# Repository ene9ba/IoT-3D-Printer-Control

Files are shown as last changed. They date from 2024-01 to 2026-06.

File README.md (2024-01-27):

# IoT-3D-Printer-Control
Control Unit with ESP 8266 to control enclosure LED, cabon filter and analyse Temperature, Fan-Spee, Flamesensor, Smokesensor

CAD files you can find at [grabcad](https://grabcad.com/library/3d-printer-enclosure-7) or [thingeverse](https://www.thingiverse.com/thing:6453549)

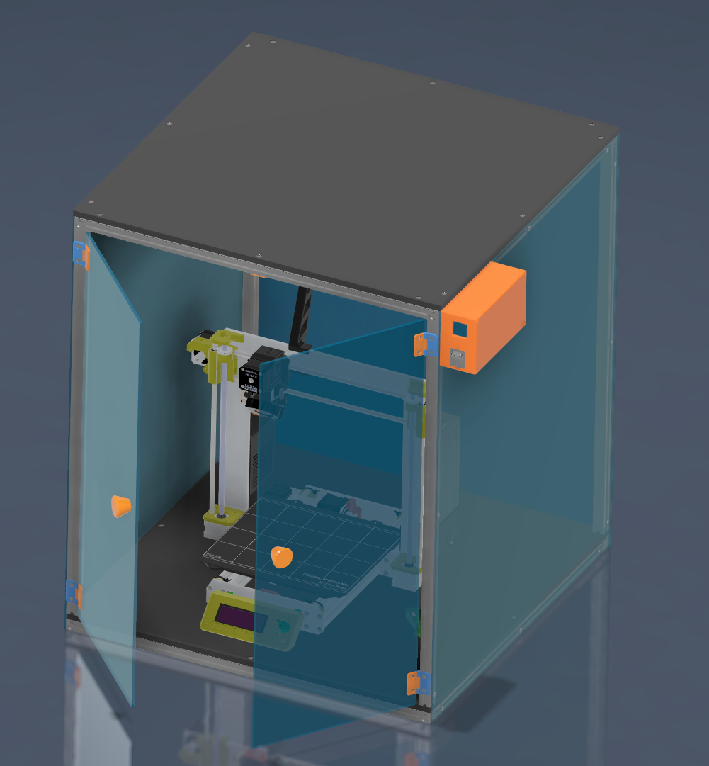
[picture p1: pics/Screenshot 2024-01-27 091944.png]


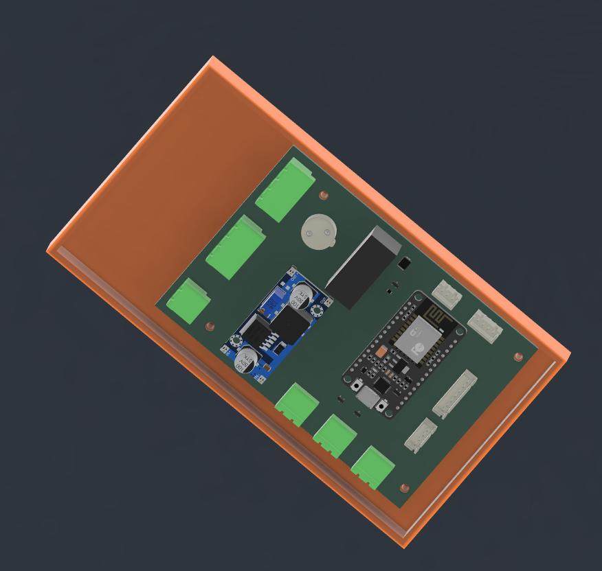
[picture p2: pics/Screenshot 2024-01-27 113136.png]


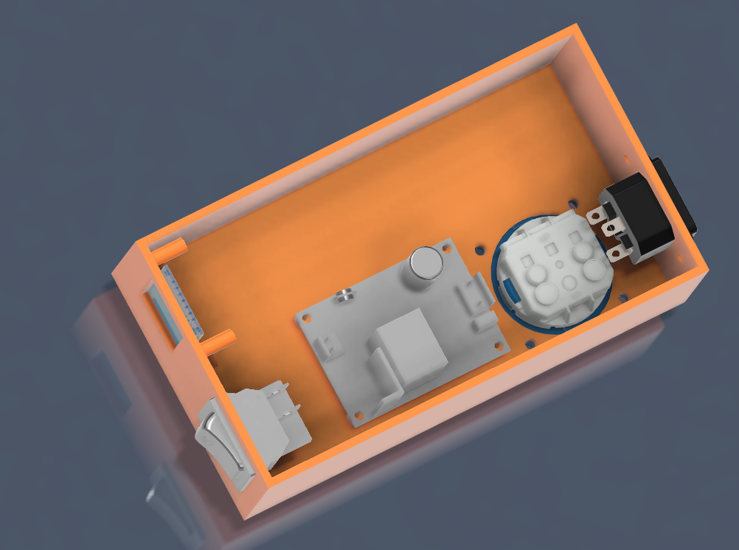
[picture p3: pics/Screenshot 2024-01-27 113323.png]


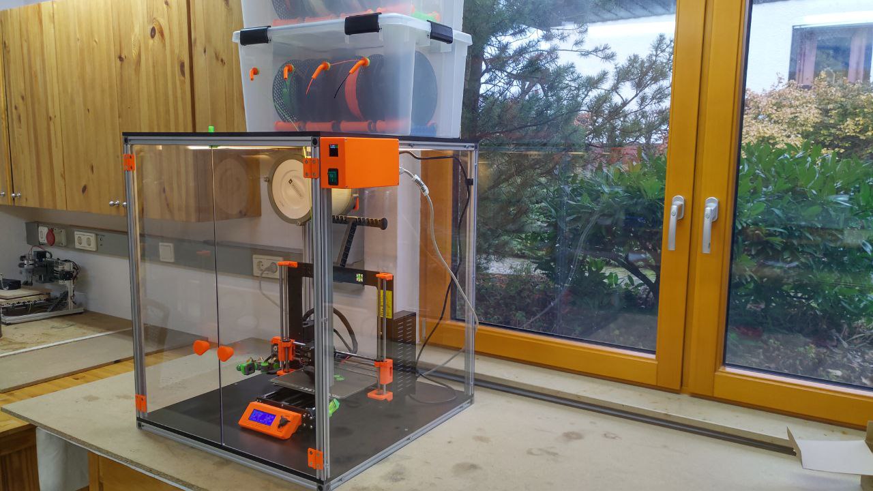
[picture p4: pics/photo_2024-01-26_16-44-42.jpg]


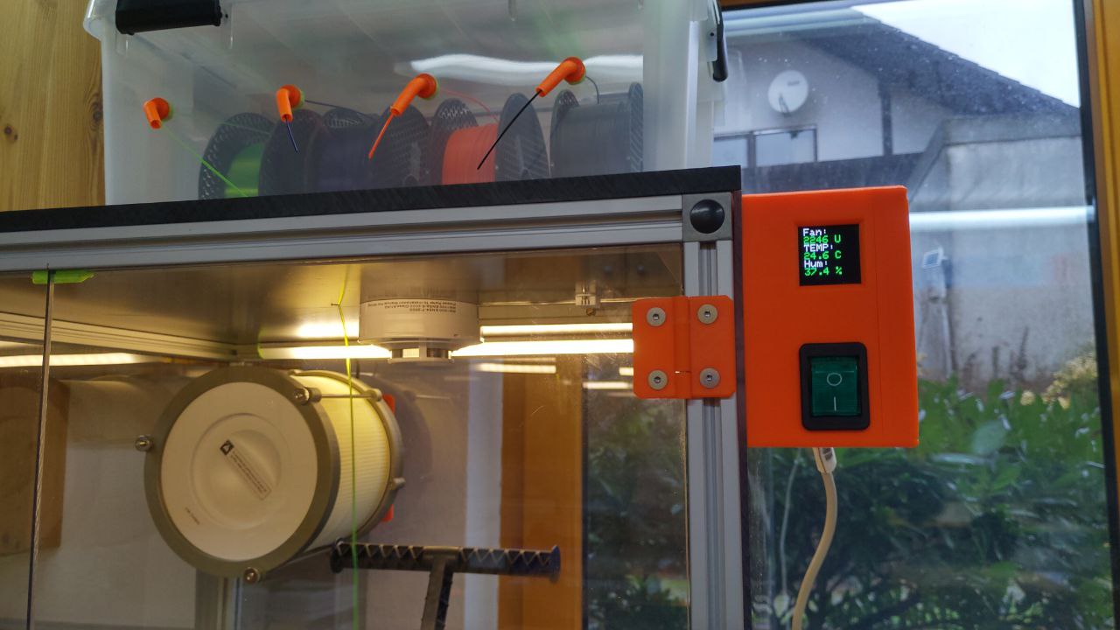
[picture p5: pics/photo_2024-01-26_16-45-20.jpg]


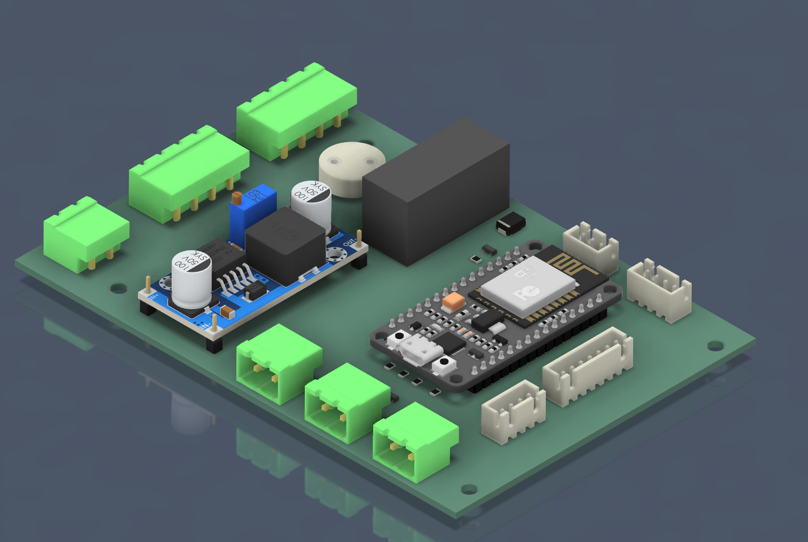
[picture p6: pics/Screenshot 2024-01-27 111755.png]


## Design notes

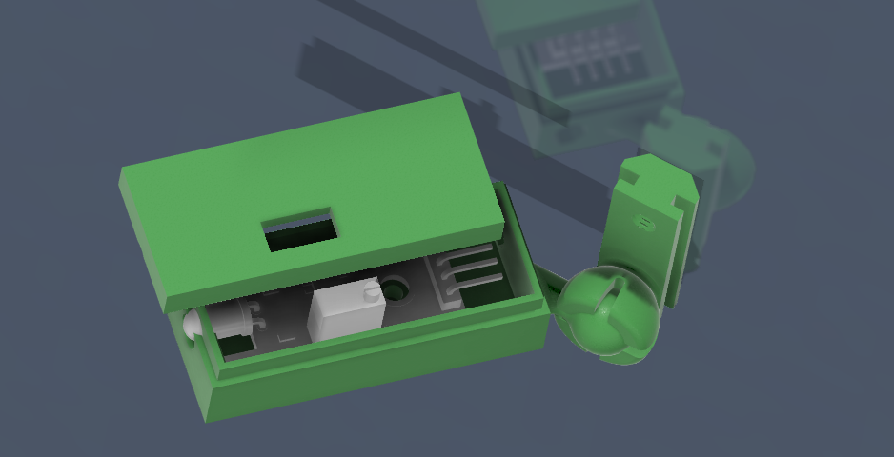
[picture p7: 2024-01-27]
pics/Screenshot 2024-01-27 111642.png

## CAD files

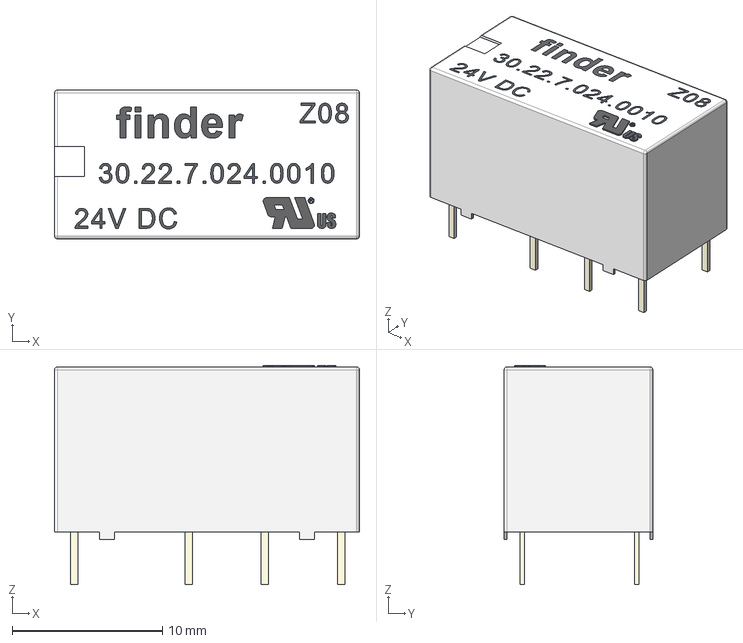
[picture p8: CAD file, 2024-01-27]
Hardware/Cabinetcontrol1/Step/relay_finder_30_22_7_024_0010.step
20.3 x 9.90 x 14.6 mm

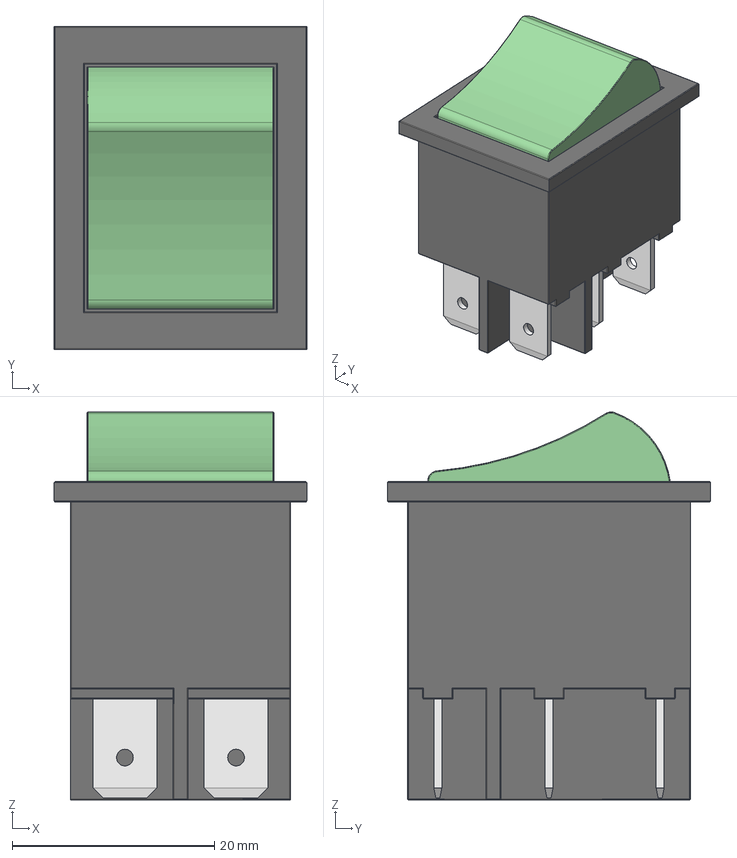
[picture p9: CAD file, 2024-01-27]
Hardware/Cabinetcontrol1/Step/Wippschalter mit Beleuchtung Serie 3652.step
25.0 x 32.0 x 38.4 mm
Flachstecker 6,3mm x 6
Schalter Körper
Grundkoerper ohne Beruehungsschutz

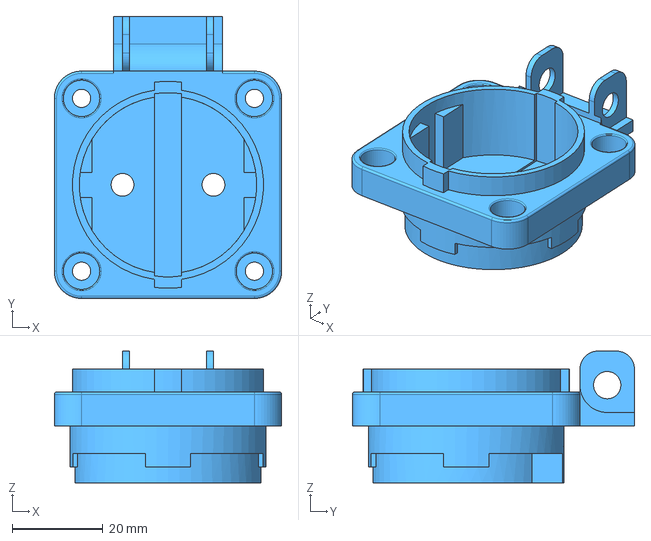
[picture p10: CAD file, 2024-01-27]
Hardware/Cabinetcontrol1/Step/Steckdose.stp
50.0 x 62.0 x 29.0 mm

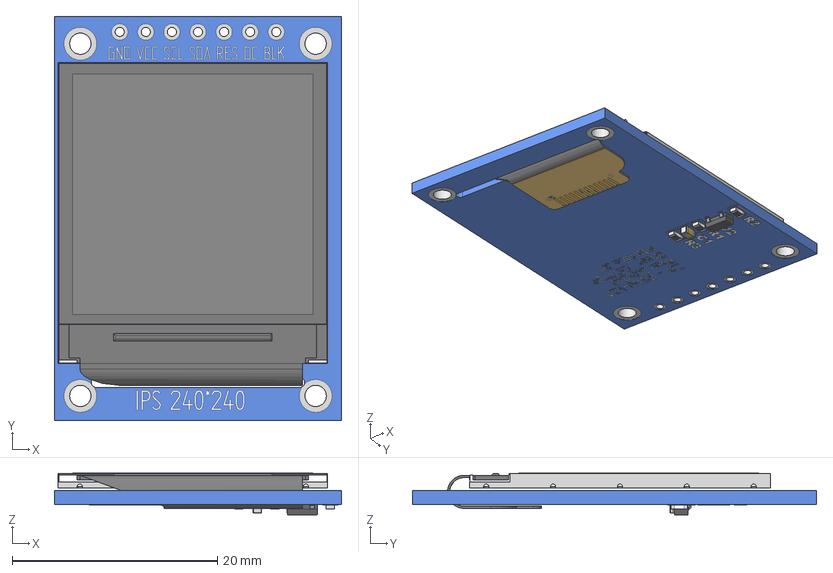
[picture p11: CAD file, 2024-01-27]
Hardware/Cabinetcontrol1/Step/1.3 TFT IPS - Module.stp
27.9 x 39.4 x 4.06 mm
1.3 TFT IPS - Board
1.3 TFT IPS - Flush Reverse Mount
0603 Resistor x 3
0603 Capacitor
SOT-23

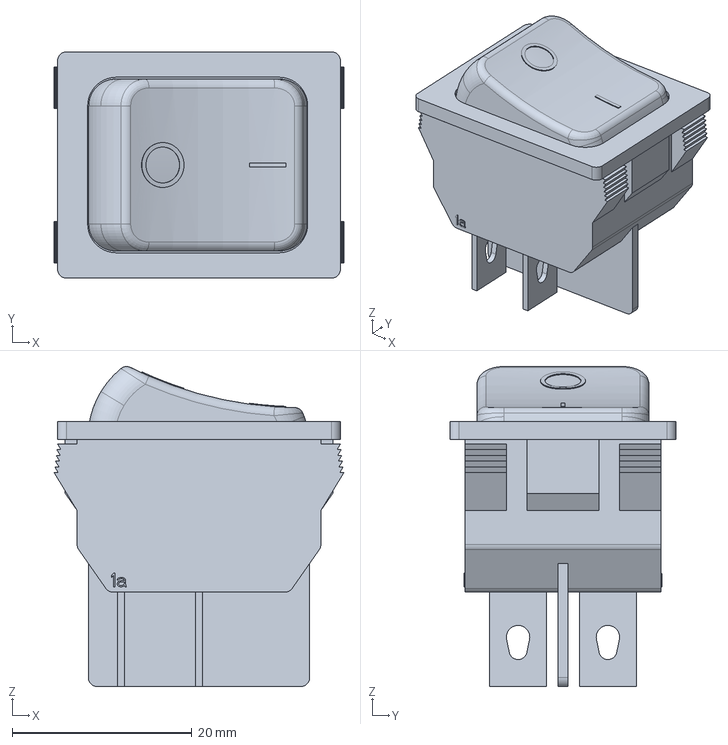
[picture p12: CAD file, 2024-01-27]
Hardware/Cabinetcontrol1/Step/Wippenschalter.stp
32.2 x 25.2 x 35.6 mm

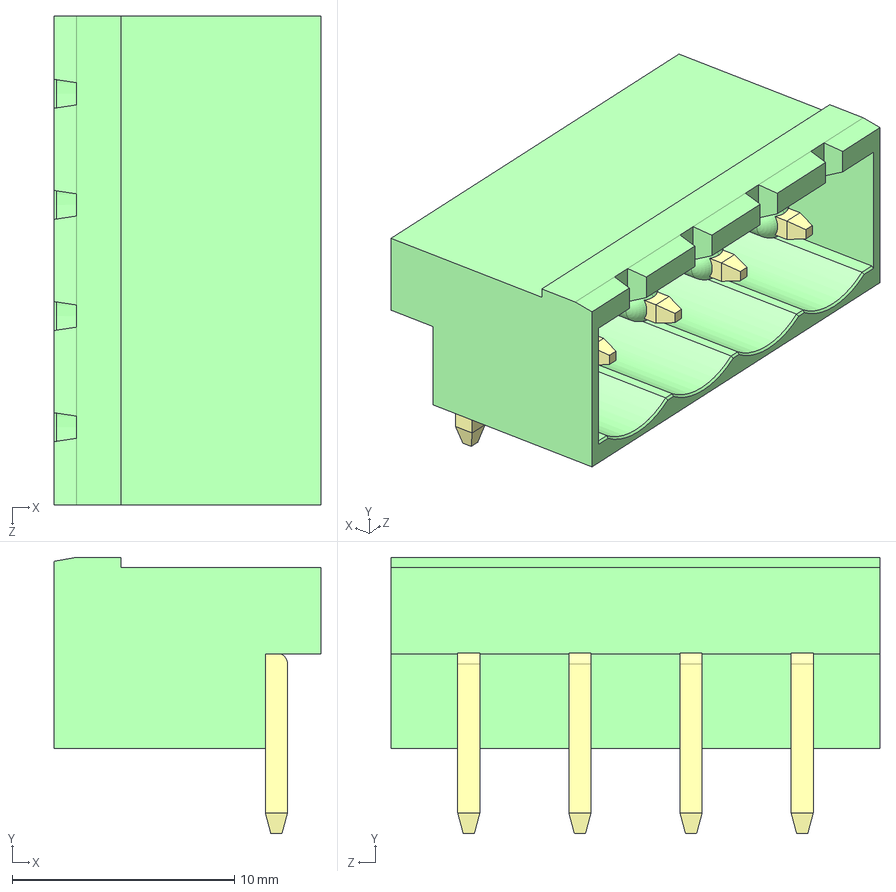
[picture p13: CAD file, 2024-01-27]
Hardware/Cabinetcontrol1/Step/Phoenix_5,08-4pol.stp
12.0 x 12.4 x 22.0 mm

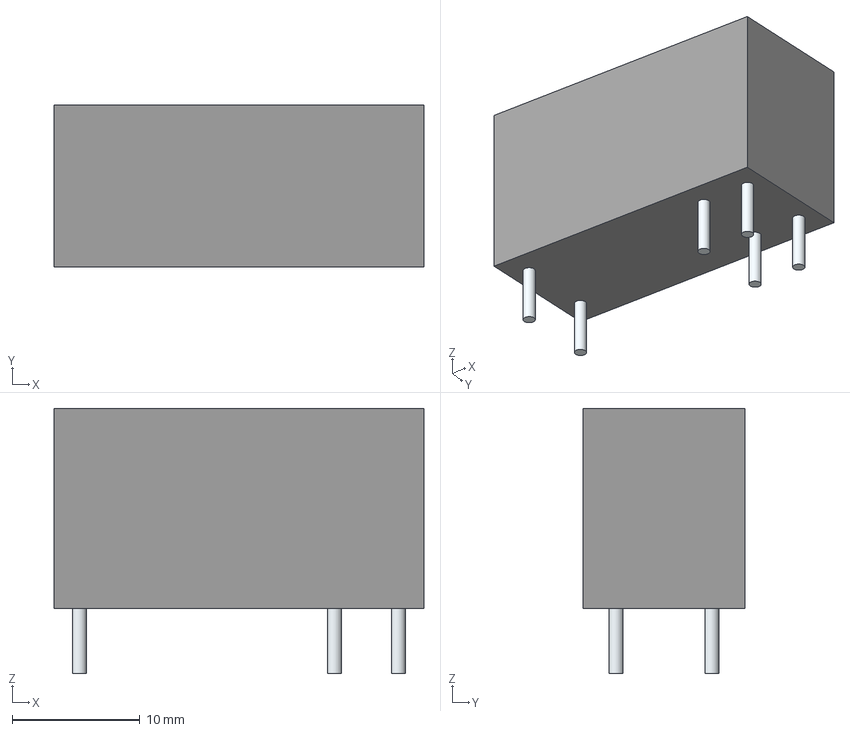
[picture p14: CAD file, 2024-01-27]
Hardware/Cabinetcontrol1/Step/Relais.stp
29.0 x 12.7 x 20.8 mm
Leads x 6

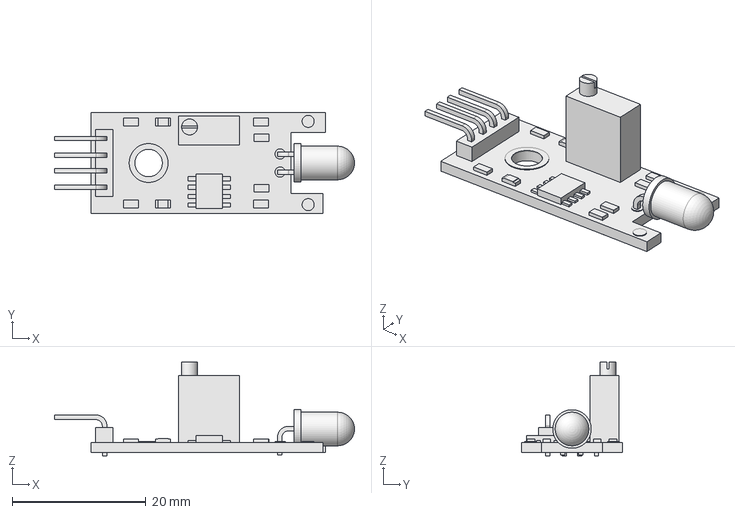
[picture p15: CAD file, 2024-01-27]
Hardware/Cabinetcontrol1/Step/KY-026_flame_IR_sensor.step
44.9 x 15.1 x 14.0 mm

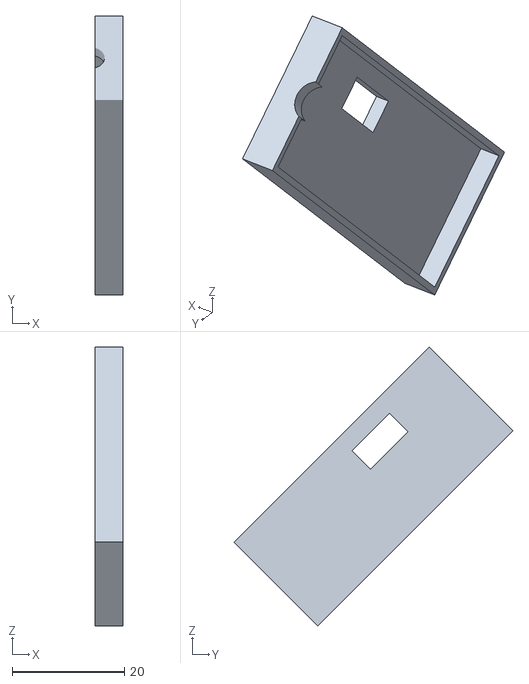
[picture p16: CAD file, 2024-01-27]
Hardware/Cabinetcontrol1/Step/SensorDach.stl
5.00 x 49.6 x 49.6

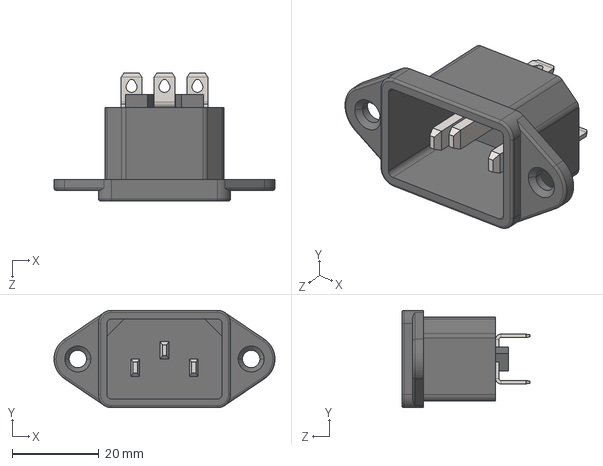
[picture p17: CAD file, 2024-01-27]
Hardware/Cabinetcontrol1/Step/Kaltgerätestecker.STEP
51.0 x 22.5 x 29.6 mm

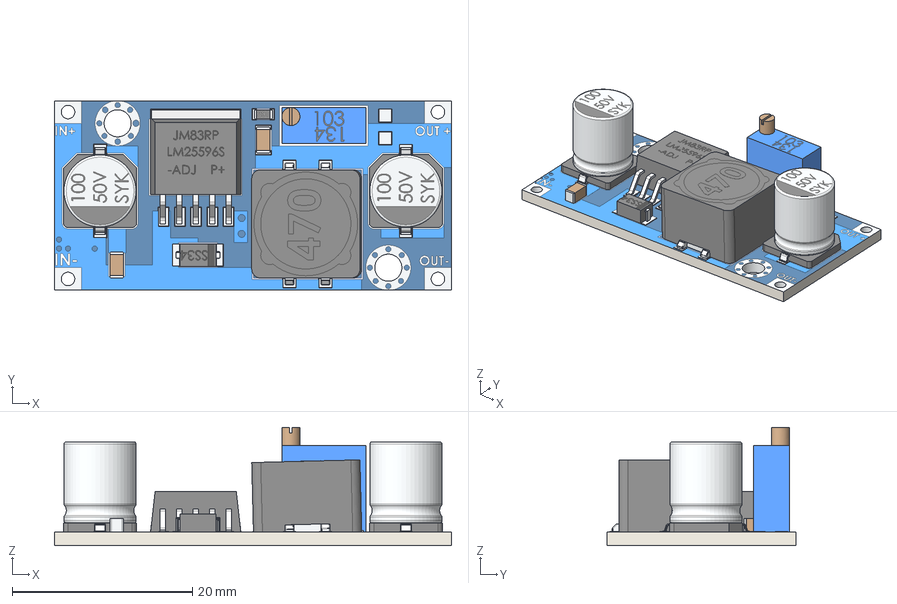
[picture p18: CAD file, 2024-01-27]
Hardware/Cabinetcontrol1/Step/LM2596.step
44.0 x 21.0 x 13.1 mm

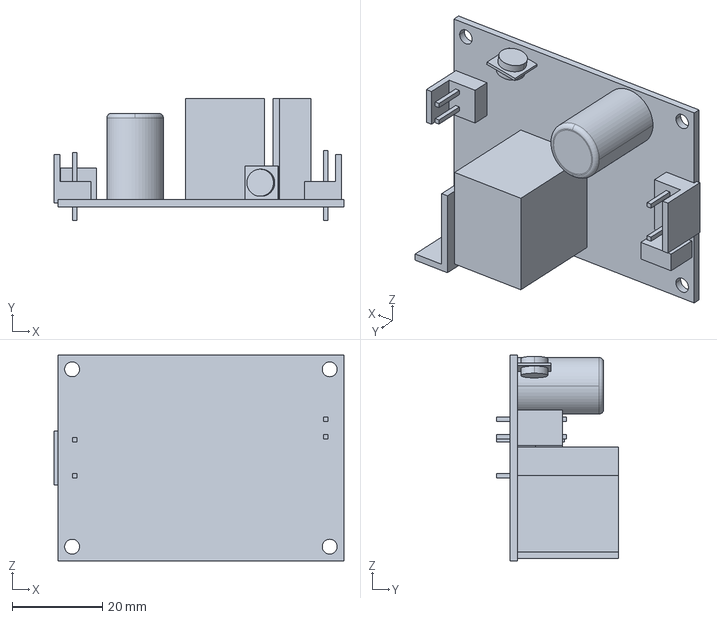
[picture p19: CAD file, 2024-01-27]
Hardware/Cabinetcontrol1/Step/Meanwell_power_supply_eps-15-3_3.stp
64.3 x 27.0 x 45.7 mm

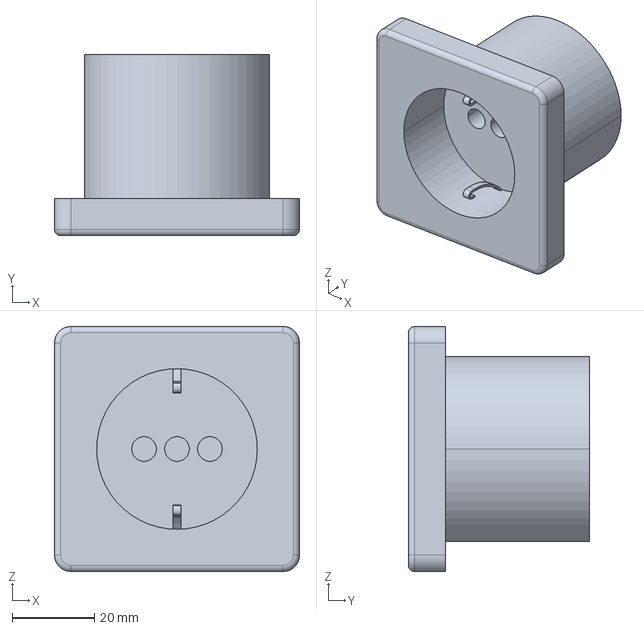
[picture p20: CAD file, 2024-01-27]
Hardware/Cabinetcontrol1/Step/Steckdose_Item.stp
59.5 x 44.0 x 59.5 mm

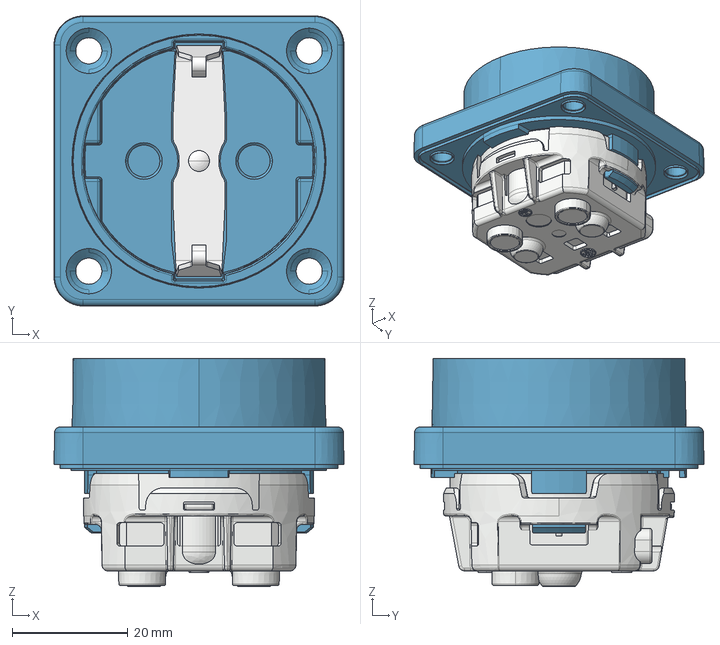
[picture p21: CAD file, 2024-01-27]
Hardware/Cabinetcontrol1/Step/Steckdose-Mennekan.stp
50.0 x 50.0 x 39.3 mm

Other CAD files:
Hardware/Cabinetcontrol1/Step/IRLML2402TRPBF.stp
Hardware/Cabinetcontrol1/Step/Phoenix-5,08-2pol.stp

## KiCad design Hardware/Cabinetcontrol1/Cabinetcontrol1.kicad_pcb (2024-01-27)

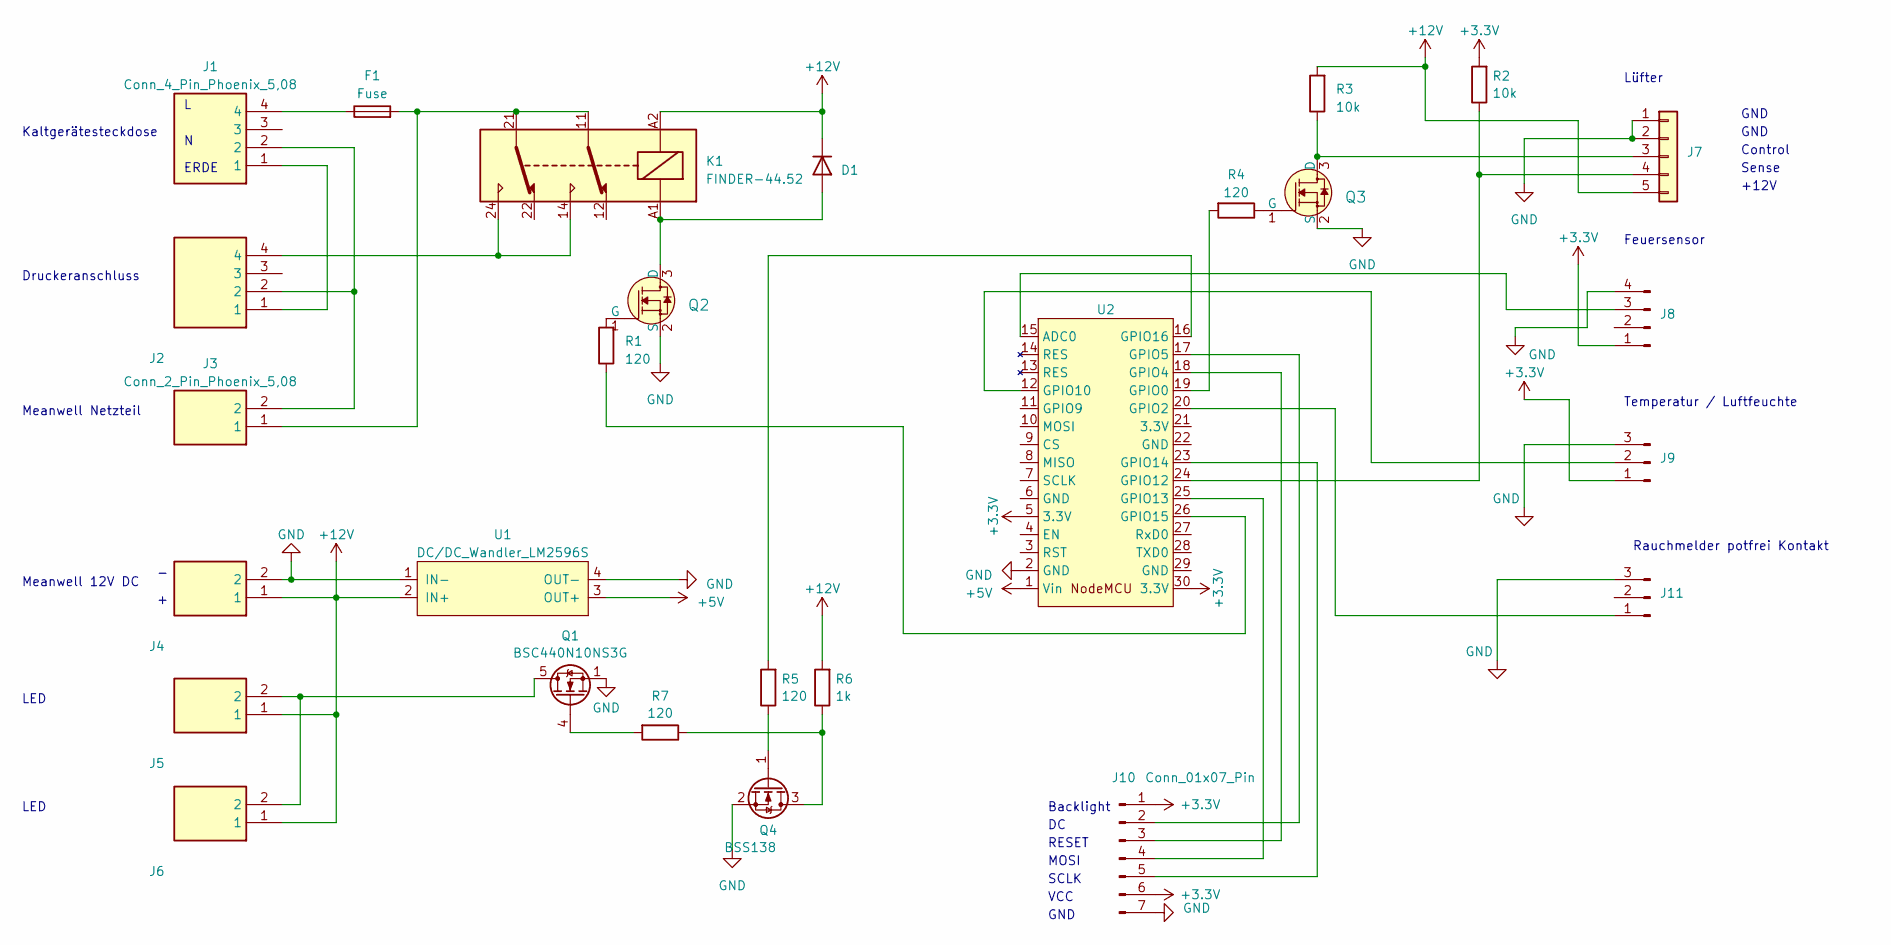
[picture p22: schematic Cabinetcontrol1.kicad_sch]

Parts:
D1: MBRS 1100 SMD Schottkydiode, 100 V, 1 A, DO-214AA; D_SMB_Handsoldering
F1: Fuse; Sicherungssockel rund
J1, J2: Conn_4_Pin_Phoenix_5,08; 1757268; Manufacturer_Part_Number 1757268; Mouser Part Number 651-1757268
J3, J4, J5, J6: Conn_2_Pin_Phoenix_5,08; 1757242; Manufacturer_Part_Number 1757242; Mouser Part Number 651-1757242
J7: Conn_01x05; JST_XH_B5B-XH-AM_1x05_P2.50mm_Vertical
J8: Conn_01x04_Pin_JST-XHP; JST_XH_B4B-XH-A_1x04_P2.50mm_Vertical
J9, J11: Conn_01x03_Pin; JST_XH_B3B-XH-A_1x03_P2.50mm_Vertical
J10: Conn_01x07_Pin; JST_XH_B7B-XH-A_1x07_P2.50mm_Vertical
K1: FINDER-44.52; Relay_DPDT_Finder_40.52
Q1: BSC440N10NS3G; TDSON-8-1
Q2, Q3: IRLML2402TRPBF; SOT95P237X112-3N; MPN IRLML2402TRPBF; Digi-Key_PN IRLML2402PBFCT-ND
Q4: BSS138; SOT-23
R1, R4, R5, R7: 120; R_0805_2012Metric_Pad1.20x1.40mm_HandSolder
R2, R3: 10k; R_0805_2012Metric_Pad1.20x1.40mm_HandSolder
R6: 1k; R_0805_2012Metric_Pad1.20x1.40mm_HandSolder
U1: DC/DC_Wandler_LM2596S; LM2596S_MODULE
U2: NodeMCU

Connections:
+3.3V: J8.1, J9.1, J10.1, J10.6, R2.2, U2.5 (3.3V), U2.30 (3.3V)
+5V: U1.3 (OUT+), U2.1 (Vin)
+12V: D1.1 (K), J4.1, J5.1, J6.1, J7.5, K1.A2, R3.2, R6.2, U1.2 (IN+)
GND: J4.2, J7.1, J7.2, J8.4, J9.3, J10.7, J11.3, Q1.1 (S), Q1.2 (S), Q1.3 (S), Q2.2 (S), Q3.2 (S), Q4.2 (S), U1.1 (IN-), U1.4 (OUT-), U2.2 (GND)
unnamed: D1.2 (A), K1.A1, Q2.3 (D)
unnamed: F1.1, J1.4
unnamed: F1.2, J3.1, K1.11, K1.21
unnamed: J1.1, J2.1
unnamed: J1.2, J2.2, J3.2
unnamed: J2.4, K1.14, K1.24
unnamed: J7.3, Q3.3 (D), R3.1
unnamed: J7.4, R2.1, U2.24 (GPIO12)
unnamed: J8.3, U2.15 (ADC0)
unnamed: J9.2, U2.12 (GPIO10)
unnamed: J10.2, U2.17 (GPIO5)
unnamed: J10.3, U2.18 (GPIO4)
unnamed: J10.4, U2.25 (GPIO13)
unnamed: J10.5, U2.23 (GPIO14)
unnamed: J11.1, U2.20 (GPIO2)
unnamed: J5.2, J6.2, Q1.5 (D)
unnamed: Q1.4 (G), R7.2
unnamed: Q2.1 (G), R1.2
unnamed: Q3.1 (G), R4.1
unnamed: Q4.3 (D), R6.1, R7.1
unnamed: Q4.1 (G), R5.1
unnamed: R4.2, U2.19 (GPIO0)
unnamed: R1.1, U2.26 (GPIO15)
unnamed: R5.2, U2.16 (GPIO16)

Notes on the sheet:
VCC
ERDE
Meanwell Netzteil
RESET
Lüfter
GND
Kaltgerätesteckdose
Backlight
Control
Druckeranschluss
Feuersensor
Meanwell 12V DC
+12V
LED
Temperatur / Luftfeuchte
Rauchmelder potfrei Kontakt
Sense
SCLK
MOSI

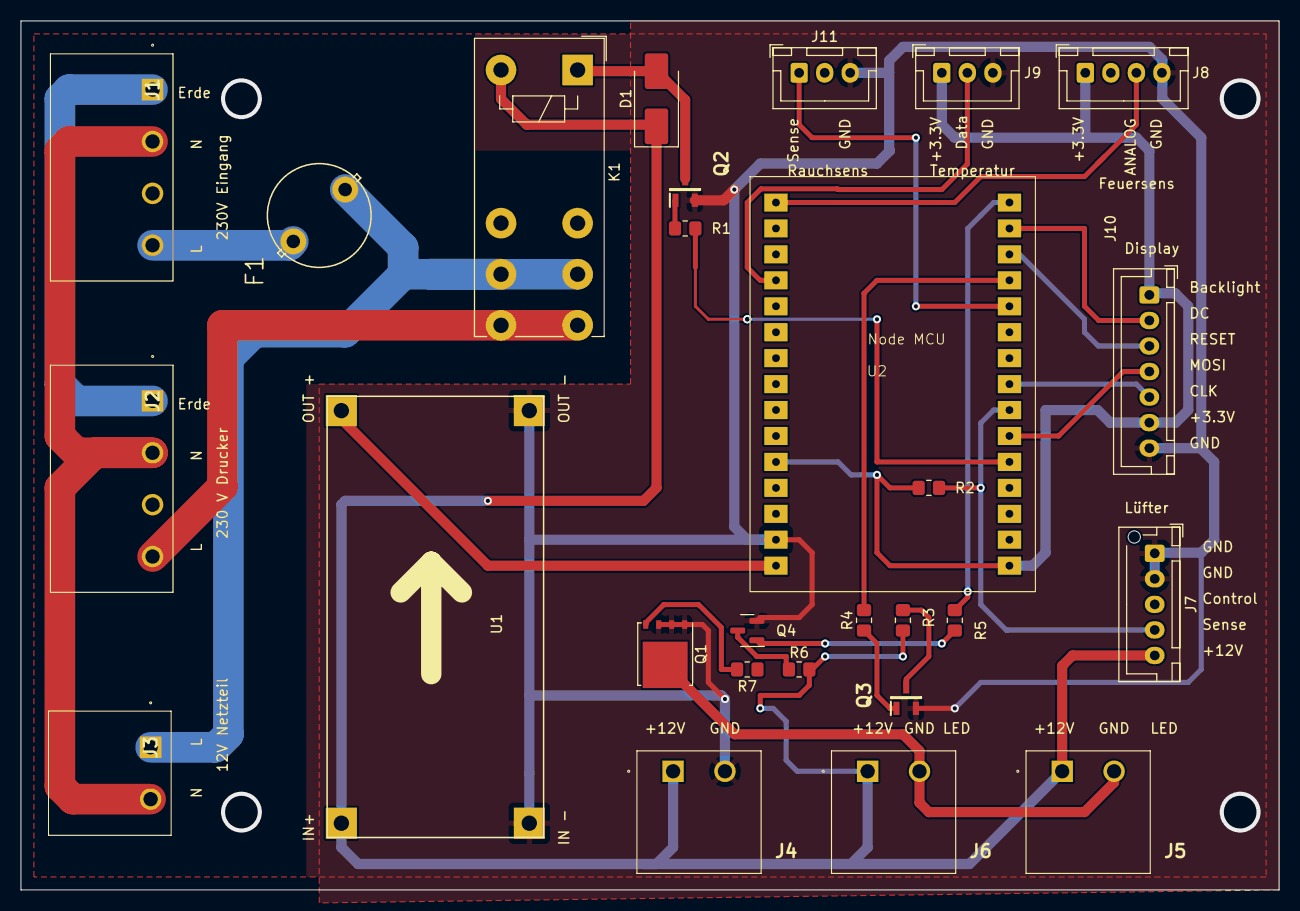
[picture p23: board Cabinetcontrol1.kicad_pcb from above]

Board: 2 copper layers, 123.2 x 85.1 mm, 27 parts (0 on the bottom side), 28 nets.

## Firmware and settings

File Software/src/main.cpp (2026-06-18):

/*
Version 1.0 v. 24.11.2023

Dieses Programm steuert die 3D Druckerbox, überwacht und steuert die
Lüfterdrehzahl, überwacht mit Feuersensor und Temperatur und Luftfeuchte,
zeigt die wesentlichen Werte in eine TFT-Display an.

Version 1.10 v. 16.03.2024 ntp hinzugefügt las message Meldung geht an mqtt
Version 1.20 v. 24.09.2024 mqtt mit user und passort, reconnect getestet
Version 1.21 v. 08.02.2026 mqtt domain name changed from docker-home to docker-home.castle
*/

//#define __DEBUG
#define _MQTT_DEBUG_

#include <Arduino.h>
#include <DHT.h>

#include <Adafruit_GFX.h>
#include <Adafruit_ST7789.h>
#include <SPI.h>



String        HOSTNAME           = "3DCabinetControl";
const char*   AUTO_CONNECT_NAME  = "IoT_CabinetControl";
//MQTT-Server Adresse
const char*   MQTT_SERVER        = "mqtt-srv1.castle";
#define MQTT_USER "mymqtt"
#define MQTT_PW   "yfAlORp1C3k70fy6XSkY"

//Portzuordnung
#define PWM                 0     // gpio 0 oder D3
#define FREQ               12     // Drehzahl Lüfter
#define DHT22_PIN          10     // DHT 22  (AM2302) - what pin we're connected to
#define RELAIS_LED         16     // Output Switch LED Flasher on
#define RELAIS             15     // Output Relais
#define ANALOG             A0     // Flame sensor
#define SMOKE               2     // Smoke Sensor

#define TFT_CS             15     // define CS
#define TFT_DC              5     // define data/command pin
#define TFT_RST             4     // define reset pin

#define DHTTYPE            DHT22




// mqtt publish values

const char* mqtt_pub_Val2     ="/openHAB/3dCabinet/Fan_rpm_actual";
const char* mqtt_pub_Val3     ="/openHAB/3dCabinet/Temperature";
const char* mqtt_pub_Val4     ="/openHAB/3dCabinet/Humidity";
const char* mqtt_pub_Val5     ="/openHAB/3dCabinet/Fire";
const char* mqtt_pub_Val6     ="/openHAB/3dCabinet/Smoke";
const char* mqtt_pub_Val7     ="/openHAB/3dCabinet/FireAnalog";
const char* mqtt_pub_Version  ="/openHAB/3dCabinet/Version";
const char* mqtt_pub_RSSI     ="/openHAB/3dCabinet/RSSI";
const char* mqtt_pub_Debug    ="/openHAB/3dCabinet/Debug";

const char* mqtt_pub_lastconnect    =  "/openHAB/3dCabinet/lastReconnect";
const char* mqtt_pub_lastmsg        =  "/openHAB/3dCabinet/lastMessage";


// mqtt subscribe values
const char* mqtt_pub_Val1     ="/openHAB/3dCabinet/Fan_rpm_target";
char    msg1[250]; 


// Global Variables
float             rpm               = 0.0;            // Lüfterdrehzahl
word              solldrehzahl      = 0;              // Solldrehzahl PWM-Wert in %
float             humidity          = 0.0;            //Stores humidity value
float             temperatur        = 0.0;            //Stores temperature value
String            smoke_detected    = "no init";      // Rauchsensor
String            fire_detected     = "no init";      // Feuersensor
word              fire_analog       = 0;
bool              alarm             = false;
bool              firealarm_trigg   = false;
word              roundrobin        = 0;

#include "Helper.h"



String Version    = "V1.21 :: ";
String AppName    = "Smart-Druckergehäuse";


//Globale Variablen 

String ipStr;
String MQTT_HostName;

// Zeitspeicher für Pseudothreads im Loop
long        thread_last_setrpm       = 0;
long        thread_last_getrpm       = 0;
long        thread_last_getTemHum    = 0;
long        thread_last_getFire      = 0;
long        thread_last_getSmoke     = 0;
long        thread_lastMsg_RSSI      = 0;
long        thread_check_system      = 0;
long        thread_show_info_display = 0;



// Schwellwert Analog Feuer erkannt
#define     FIRETRIGGER       360     // Schwellwert Feuertrigger Alarm, wenn dieser Wert unterschritten
#define     MIN_ERR_RPM_100  2000     // Minimal erwartete Drehzahl Lüfter bei Sollwert 100 % 
#define     MIN_WARN_RPM_100 1000     // Minimal erwartete Drehzahl Lüfter bei Sollwert 100 % 
#define     MAX_TEMP          45      // Maximale Temperatur im Gehäuse
#define     MIN_RPM         1000      // Minimale Drehzahl Lüfter




DHT dht(DHT22_PIN,DHTTYPE);
Adafruit_ST7789 tft = Adafruit_ST7789(TFT_CS, TFT_DC, TFT_RST);



 


void publish_MQTT_Values()

{
    //Zeit seit letztem Durchlauf berechen und die Sekunden in value hochz?hlen  
    long now = millis();

    if (now - thread_lastMsg_RSSI < 3000) return;

    int rssi = WiFi.RSSI();
    Serial.print("RSSI: ");
    Serial.print(rssi);
    Serial.println(" db");

    // publish rssi
    itoa(rssi,msg1,10);
    client.publish(mqtt_pub_RSSI,msg1);

    // publish rmp acutal
    sprintf(msg1,"%.1f",rpm);
    client.publish(mqtt_pub_Val2,msg1);

    // publish temperature & humitidy
    sprintf(msg1,"%.1f",temperatur);
    client.publish(mqtt_pub_Val3,msg1);
    sprintf(msg1,"%.1f",humidity);
    client.publish(mqtt_pub_Val4,msg1);

    // Rauch und Feuer
    client.publish(mqtt_pub_Val6,smoke_detected.c_str());
    client.publish(mqtt_pub_Val5,fire_detected.c_str());
    sprintf(msg1,"%d",fire_analog);
    client.publish(mqtt_pub_Val7,msg1);

    set_time_string();  
    client.publish(mqtt_pub_lastmsg,dt);

    thread_lastMsg_RSSI = millis();

}












 void get_rpm() {
      unsigned long     highpulse = 0;
      unsigned long     lowpulse = 0;
      double            frequency = 0.0;



      //Zeit seit letztem Durchlauf berechen und die Sekunden in value hochz?hlen  
      long now = millis();
      if (now - thread_last_getrpm < 1000) return;

      highpulse = pulseIn(FREQ, HIGH);
      lowpulse = pulseIn(FREQ, LOW);

      // wenn timeout wird 0 zurück geliefert, dann steht der Lüfter
      if(highpulse !=0 && lowpulse !=0) {
            // berechne drehzahl
            frequency = 1.0 / ((highpulse + lowpulse) / 1000000.0);
            rpm = frequency * 60;

      }
      else rpm = 0;

     
      #ifdef _MQTT_DEBUG_
            
      
            sprintf(msg1,"highpulse: %lu  us, Lowpulse: %lu  us Frequenz: %.0f  Hz Drehzal: %.0f",highpulse, lowpulse, frequency, rpm);
            mqttDebugInfo(msg1);
            Serial.println(msg1);
      #else
            Serial.print(msg1);
      #endif
            

      thread_last_getrpm = now;
      return;
}

void set_rpm(int sollwert) {
      //Zeit seit letztem Durchlauf berechen und die Sekunden in value hochz?hlen  
      long now = millis();
      if (now - thread_last_setrpm < 1000) return;

      float soll = (100 - sollwert) * 2.55;
      analogWrite(PWM,(int)soll);
      #ifdef __DEBUG
      Serial.print("Sollwert: "); Serial.print(sollwert); Serial.print("PWM: "); Serial.println((int(soll))); 
      #endif  

      thread_last_setrpm = now;
      return;
}


void get_Temp_Hum() {
      //Zeit seit letztem Durchlauf berechen und die Sekunden in value hochz?hlen  
      long now = millis();
      if (now - thread_last_getTemHum < 2000) return;

      humidity = dht.readHumidity();
      temperatur = dht.readTemperature();
      

      #ifdef __DEBUG
      Serial.print("Luftfeuchte: "); Serial.print(humidity); Serial.print(" %, Temperatur: "); Serial.print(temperatur); Serial.println(" Grad Celsius"); 
      #endif  
    

      thread_last_getTemHum = now;
      return;
}


void get_FireSense() {
      //Zeit seit letztem Durchlauf berechen und die Sekunden in value hochz?hlen  
      long now = millis();
      if (now - thread_last_getFire < 500) return;

      fire_analog = analogRead(ANALOG);
      
      

      #ifdef __DEBUG
      Serial.print("Feuersensor: "); Serial.println(fire_analog); //Serial.print(" %, Temperatur: "); Serial.print(temperatur); Serial.println(" Grad Celsius"); 
      #endif  

      
      if (fire_analog > FIRETRIGGER) fire_detected = "OK"; else fire_detected = "FIRE";


      thread_last_getFire = now;
      return;


}

void get_SmokeSense() {
      //Zeit seit letztem Durchlauf berechen und die Sekunden in value hochz?hlen  
      long now = millis();
      if (now - thread_last_getSmoke < 500) return;

      int val = digitalRead(SMOKE);
      
      

      #ifdef __DEBUG
      Serial.print("Rauch: "); Serial.println(val); //Serial.print(" %, Temperatur: "); Serial.print(temperatur); Serial.println(" Grad Celsius"); 
      #endif  
      if (val != 0) smoke_detected = "OK"; else smoke_detected = "SMOKE";

      thread_last_getSmoke = now;
      return;


}


void Init_System() {

      bool check = true;
      alarm = false;
      
      tft.fillScreen(ST77XX_BLACK);
      tft.setCursor(0, 0);
      tft.setTextColor(ST77XX_ORANGE);
      tft.setTextSize(4);
      tft.println(" System");
      tft.println(" Check");
      delay(1000);

      
      tft.fillScreen(ST77XX_BLACK);
      tft.setCursor(0, 0);

      // stetze MAX Drehzahl und messe Umdrehungen
      tft.setTextColor(ST77XX_WHITE);
      tft.print(" FAN:  ");

      set_rpm(100);
      int pos = 120;
      for (int i=0; i<10; i++) {
            tft.setCursor(pos, 0);
            tft.setTextColor(ST77XX_BLACK);
            sprintf(msg1," %1.f U", rpm);
            tft.print(msg1);
            get_rpm();
            tft.setTextColor(ST77XX_WHITE);
            tft.setCursor(pos, 0);
            sprintf(msg1," %1.f U", rpm);
            tft.print(msg1);
            delay(500);
                  

      }
      tft.setCursor(pos, 0);
      tft.setTextColor(ST77XX_BLACK);
      tft.print(msg1);
            
      tft.setCursor(pos, 0);
      if (rpm < MIN_ERR_RPM_100) {
            tft.setTextColor(ST77XX_RED);
            tft.println("ERR");
            check = false;
      }
      else {
            tft.setTextColor(ST77XX_GREEN);
            tft.println("O.K.");
      }
      delay(100);
      
      // Prüfe Temperatur auf Plausibilität      
      tft.setTextColor(ST77XX_WHITE);
      tft.print(" TEMP: ");
      get_Temp_Hum();
      if (temperatur < 10 || temperatur > 40 ) {
            tft.setTextColor(ST77XX_RED);
            tft.println("ERR");
            check = false;
      }
      else {
            tft.setTextColor(ST77XX_GREEN);
            tft.println("O.K.");
      }
      
      
      // Prüfe Analogstpannung Feuersensor
      tft.setTextColor(ST77XX_WHITE);
      tft.print(" FLAME:");
      get_FireSense();
      if (fire_detected != "OK") {
            tft.setTextColor(ST77XX_RED);
            tft.println("ERR");
            check = false;
      }
      else {
            tft.setTextColor(ST77XX_GREEN);
            tft.println("O.K.");
      }
      
      // Prüfe Eingang Rauchmelder
      tft.setTextColor(ST77XX_WHITE);
      tft.print(" Smoke:");
      get_SmokeSense();
      if (smoke_detected != "OK") {
            tft.setTextColor(ST77XX_RED);
            tft.println("ERR");
            check = false;
      }
      else {
            tft.setTextColor(ST77XX_GREEN);
            tft.println("O.K.");
      }
 
      if (!check) {
            tft.setTextColor(ST77XX_RED);
            tft.println(""); tft.print("  ERROR");
            delay(10000);

      }
      // Every Thing is o.k. Relay on, LED on Fan on
      else {
            delay(1000);
            tft.setTextColor(ST77XX_GREEN);
            tft.println(""); tft.print("  O.K.");
            
            solldrehzahl = 50;
            tft.fillScreen(ST77XX_BLACK);
            tft.setCursor(0, 0);
            delay(500);
            digitalWrite(RELAIS_LED,LOW);    

            delay(500);
            tft.init(240, 240, SPI_MODE2);
            tft.setRotation(1); 
            delay(500);
            pinMode(FREQ,INPUT);     // Fan pwm control
            


      }
      

}


// prüft auf unregelmäßigkeiten uns schaltet bei Gefahr aus
void check_system() {

        
      //Zeit seit letztem Durchlauf berechen und die Sekunden in value hochzählen  
      long now = millis();
      if (now - thread_check_system < 500) return;

      String errtext="none";
      
      // Überwache Drehzahl
      if (rpm < MIN_RPM) {
            errtext = "\n ERR Fan";
            alarm = true;
      }
      
      
      // Überwache Temperatur      
      if (temperatur > MAX_TEMP) {
            errtext = "\n ERR Temp";
            alarm = true;
      }
      
      // Überwache Analogstpannung Feuersensor
      if (fire_detected != "OK") {
            errtext = "\n ERR Fire";
              firealarm_trigg = true;
  //          alarm = true;
      }
      
      // Überwache Eingang Rauchmelder
      if (smoke_detected != "OK") {
            errtext = "\n ERR Smoke";
            alarm = true;
      }
      
     // System, stoppen bei Fehler
     if (alarm) {

      digitalWrite(RELAIS_LED,HIGH);
      delay(1000);
      set_rpm(0);
      delay(200);
      tft.fillScreen(ST77XX_RED);
      bool alternate = false;
      while(true) {

          if (alternate) {
            tft.setTextColor(ST77XX_BLUE);
            alternate = false;
          }
          else { 
            tft.setTextColor(ST77XX_WHITE);
            alternate = true;
          }
          tft.setCursor(0, 0);
          tft.println(errtext);  
          get_rpm();
          get_FireSense();
          publish_MQTT_Values();
          ArduinoOTA.handle();
          //check_mqtt_connect();
          client.loop();
          delay(500);  
      }

     } 
     
      thread_check_system = now;


}


void show_info_display() {

       //Zeit seit letztem Durchlauf berechen und die Sekunden in value hochz?hlen  
      long now = millis();
      if (now - thread_show_info_display < 5000) return;

      

      tft.setCursor(0, 0);
      
      switch (roundrobin) {

          case 0: // Drehzahl anzeigen
                  tft.setCursor(0, 0);
                  tft.fillScreen(ST77XX_BLACK);
                  tft.setTextColor(ST77XX_WHITE);
                  tft.println(" Fan:");
                  sprintf(msg1," %.f U", rpm);
                  if (rpm < MIN_ERR_RPM_100) tft.setTextColor(ST77XX_RED);
                  else 
                    if (rpm < MIN_WARN_RPM_100) tft.setTextColor(ST77XX_YELLOW);
                    else tft.setTextColor(ST77XX_GREEN);

                  tft.println(msg1);
                   
                  // Temperatur und Feuchte anzeigen
                  tft.setTextColor(ST77XX_WHITE);
                  tft.println(" TEMP:");
                  tft.setTextColor(ST77XX_GREEN);
                  sprintf(msg1," %.1f C", temperatur);
                  tft.println(msg1);

                  tft.setTextColor(ST77XX_WHITE);
                  tft.println(" Hum:");
                  tft.setTextColor(ST77XX_GREEN);
                  sprintf(msg1," %.1f %%", humidity);
                  tft.println(msg1);
                  break;
          case 1: // Status Rauch und Feuer
                  tft.setCursor(0, 0);
                  tft.fillScreen(ST77XX_BLACK);
                  tft.setCursor(0, 0);
      
                  // Prüfe Analogstpannung Feuersensor
                  tft.setTextColor(ST77XX_WHITE);
                  tft.print(" FLAME:");
                  if (firealarm_trigg) {
                        tft.setTextColor(ST77XX_RED);
                        tft.println("ERR");
                  }
                  else {
                        tft.setTextColor(ST77XX_GREEN);
                        tft.println("O.K.");
                  }
      
                  // Prüfe Eingang Rauchmelder
                  tft.setTextColor(ST77XX_WHITE);
                  tft.print(" Smoke:");
                  if (smoke_detected != "OK") {
                  tft.setTextColor(ST77XX_RED);
                  tft.println("ERR");
                  }
                  else {
                              tft.setTextColor(ST77XX_GREEN);
                              tft.println("O.K.");
                  }
                  break;
       
                  


      }
      
      roundrobin++;
      if (roundrobin == 2) roundrobin = 0;
      thread_show_info_display = now;
      

}



void setup() {
      
      pinMode(PWM,                OUTPUT);     // Fan pwm control
      pinMode(RELAIS_LED,         OUTPUT);     // Fan pwm control
      pinMode(RELAIS,             OUTPUT);     // Relais power control      
      pinMode(SMOKE,               INPUT);     // Smoke sensor

      configTime(MY_TZ, MY_NTP_SERVER);
     
      digitalWrite(RELAIS_LED,HIGH);  
      // pwm frequency
      analogWriteFreq(25000); 
      set_rpm(0);  
      
      // Serielle Schnittstelle init      
      Serial.begin(19200);
      
      Serial.println(".. starting up");
      
       

      // Temperature & Humidity init
      dht.begin();
      // init display
      tft.init(240, 240, SPI_MODE2); 
      tft.setSPISpeed(8500000);
      pinMode(FREQ,                INPUT);     // Fan pwm control
      // achtung wichtig, tft class initialisiert Mosi um, deshalb danach Init

      tft.setTextSize(4);
      tft.setTextColor(ST77XX_ORANGE);
      tft.setRotation(1);               // turn disply 90 degree left and blank screen
      tft.setTextWrap(false);
      tft.fillScreen(ST77XX_BLACK);

      tft.setCursor(0, 0);
      tft.println(Version);
      tft.println("Startup");
      delay(1000);

      // Fan off
      analogWrite(PWM , 255);
      
      Serial.println("Init WiFimanager");
      tft.println("WiFi");
      init_WiFiManger();

      init_OTA(); 
      Serial.println("Init OTA");
      tft.println("OTA");

      // Verbindung mit mqtt-Server aufbauen
      setup_mqtt();
      Serial.println("Init MQTT");
      tft.println("MQTT");
      
      // publish version
      set_time_string();
      String out=Version+AppName+" startup at "+dt;
      Serial.println(out);
      out.toCharArray(msg1,75);
      client.publish(mqtt_pub_Version, msg1);
      delay(1000);

      Init_System();
  
  
      
}








/******************************************************************************************************************
  * void loop() 
  * Program Start init
*******************************************************************************************************************/

void loop() 
{
          
          // Stautus lesen und in globale Variable schreiben          
          get_rpm();
         
          set_rpm(solldrehzahl);

          get_Temp_Hum();

          get_FireSense();

          get_SmokeSense();

          check_system();

          show_info_display();

          publish_MQTT_Values();
          
          // Regelmäßig abfragen, ob ein OTA Update ansteht
          ArduinoOTA.handle();
              
          
          //WiFi Verbindung prüfen
          if (!client.connected()) 
          {
            mqtt_reconnect();
          }
          
          
          client.loop();

}

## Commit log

2024-03-16 Version 1.10 v. 16.03.2024 ntp hinzugefügt las message Meldung geht an mqtt
2024-09-24 Version 1.20 v. 24.09.2024 mqtt mit user und passort, reconnect getestet
    [1.3 TFT IPS - Module.stp, Cabinetcontrol1.kicad_pcb, Cabinetcontrol1.kicad_sch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]
2026-02-08 Version 1.21 v. 08.02.2026 mqtt domain name changed from docker-home to docker-home.castle
